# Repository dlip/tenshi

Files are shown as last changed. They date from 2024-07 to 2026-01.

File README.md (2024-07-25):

# Tenshi Keyboard

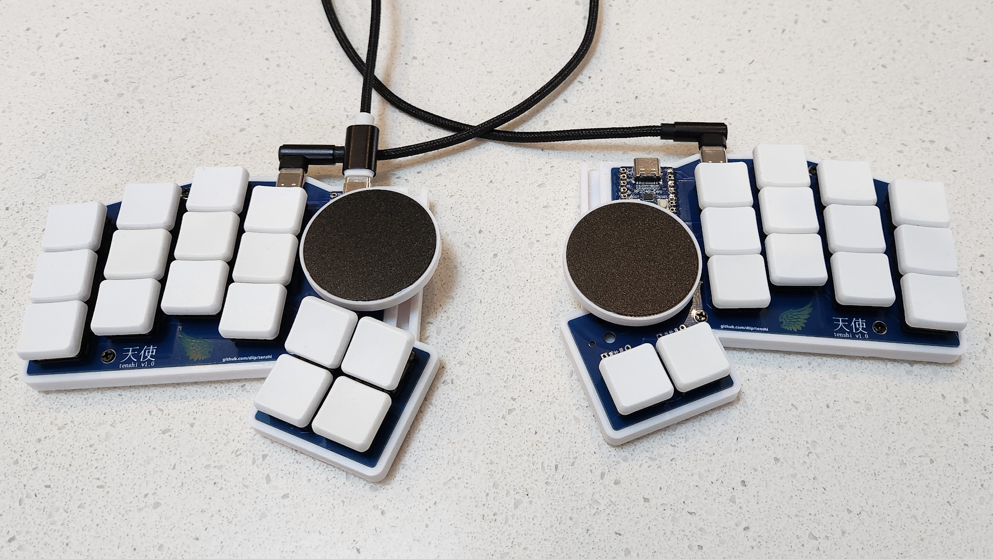
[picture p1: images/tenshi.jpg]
Tenshi


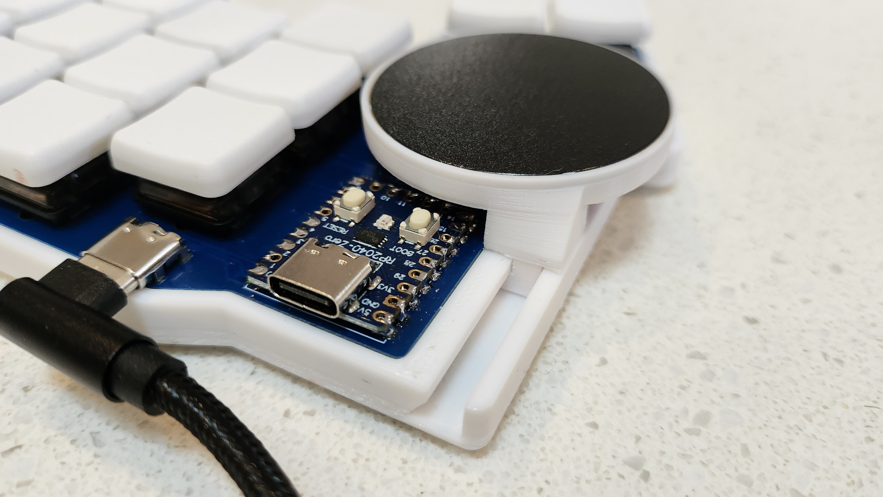
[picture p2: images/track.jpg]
Track


- RP2040-Zero controllers
- Split using USB-C to connect the halves
- Slide-adjustable Dual Cirque 40mm trackpads
- [QMK Firmware](https://github.com/dlip/qmk_firmware/tree/dlip/keyboards/tenshi)
- Custom PCB and case
- Name from Japanese means angel (the trackpads are the halos)

## BOM

- PCBs - send the [Gerber](kicad/gerber_to_order) file to the PCB manufacturer of your choice
- 2 x RP2040-Zero
- 2 x HRO TYPE-C-31-M-12 USB C female ports
- 2 x USB-C cables
- 0-2 x Cirque 40mm Trackpads TM040040-2024-302 with flat overlay
- 0-2 x Hirose FH12-12S-0.5SH FFC/FPC connectors
- 0-2 FFC/FPC cables - 5cm length, 12 position, 0.5mm pitch, same-sided contacts
- 32 x 1N4148 SOD-123 Diodes
- 32 x kailh hotswap sockets
- 32 x low profile choc switches and keycaps
- 6 x Knurled Insert Nuts M2 x 3mm Length x 3.5mm outer diameter
- 6 x M2 4mm flat head screws
- 8 x Rubber feet

## Printables

The .stls are in the [printables](./printables) folder and there is also the [OnShape Project](https://cad.onshape.com/documents/9fc41580bdc06f2de5a54d4e/w/2ac3b2b1ad9676183a17550a/e/836a95015accbfb788e70834) in case you want to make modifications.

## Build Pics

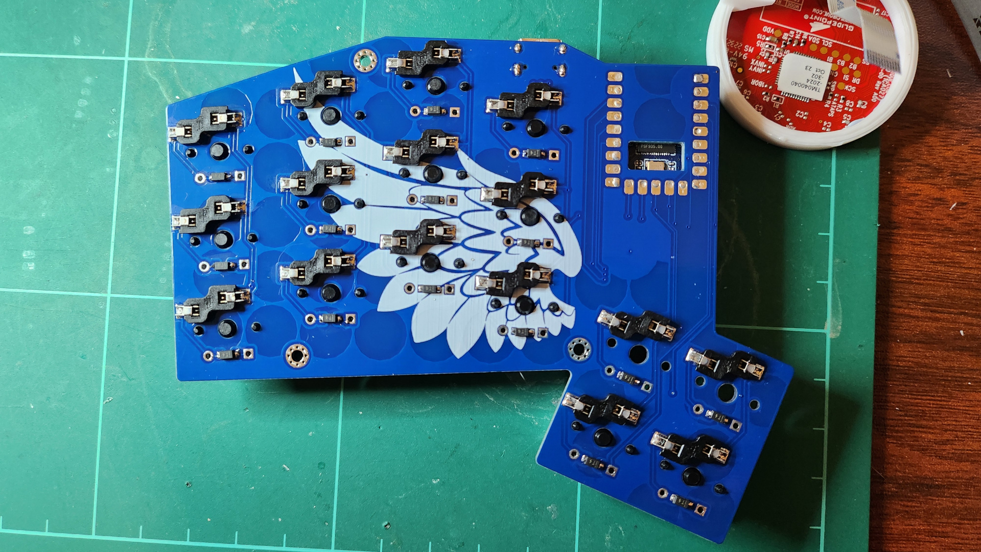
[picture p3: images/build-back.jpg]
Back


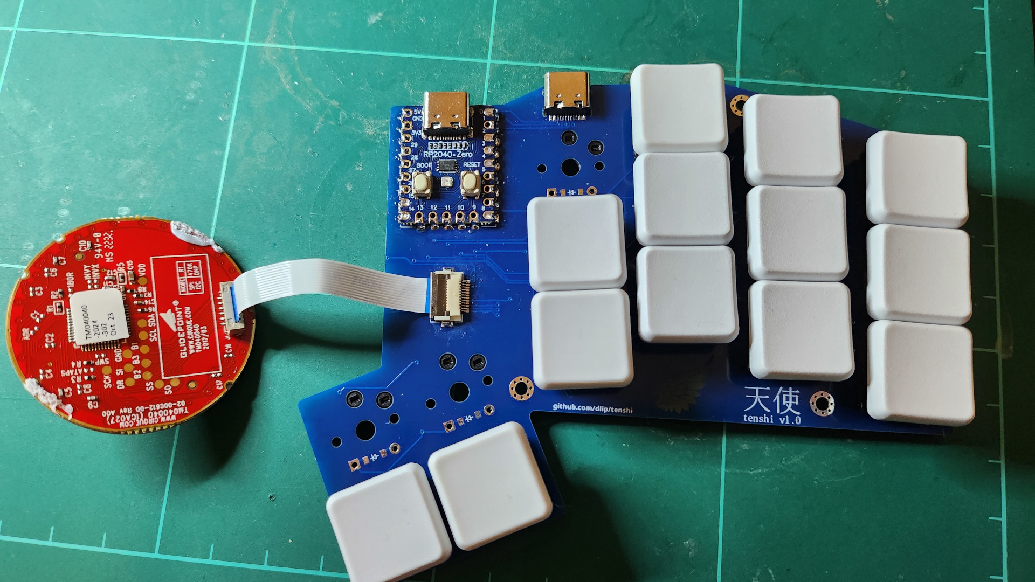
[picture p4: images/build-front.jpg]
Front


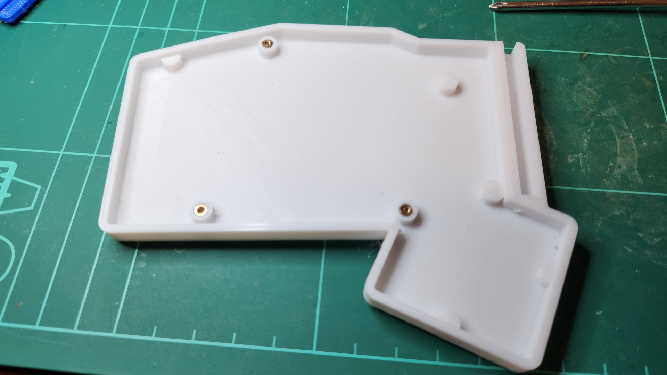
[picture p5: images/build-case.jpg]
Case


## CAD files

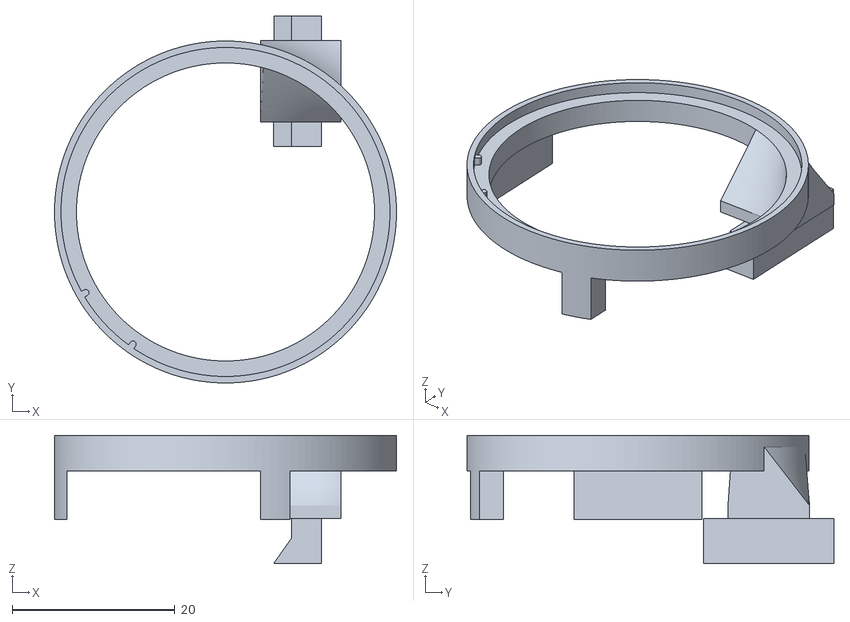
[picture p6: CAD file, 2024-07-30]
printables/Cirque trackpad left.stl
42.0 x 45.1 x 15.7

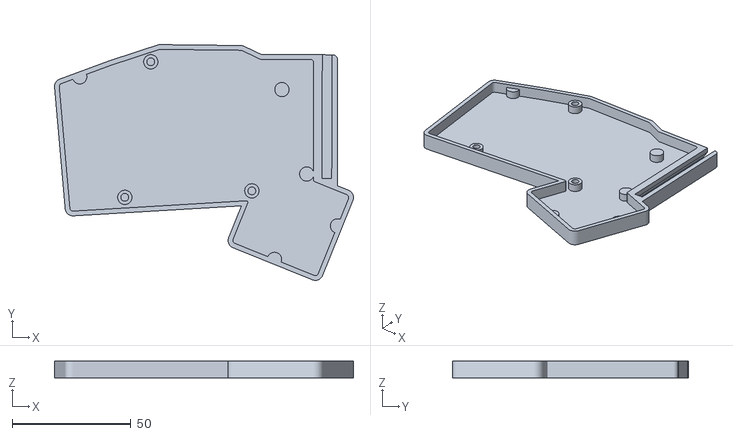
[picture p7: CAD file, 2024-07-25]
printables/base left.stl
125.7 x 99.1 x 7.00

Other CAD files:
printables/Cirque trackpad right.stl
printables/base right.stl

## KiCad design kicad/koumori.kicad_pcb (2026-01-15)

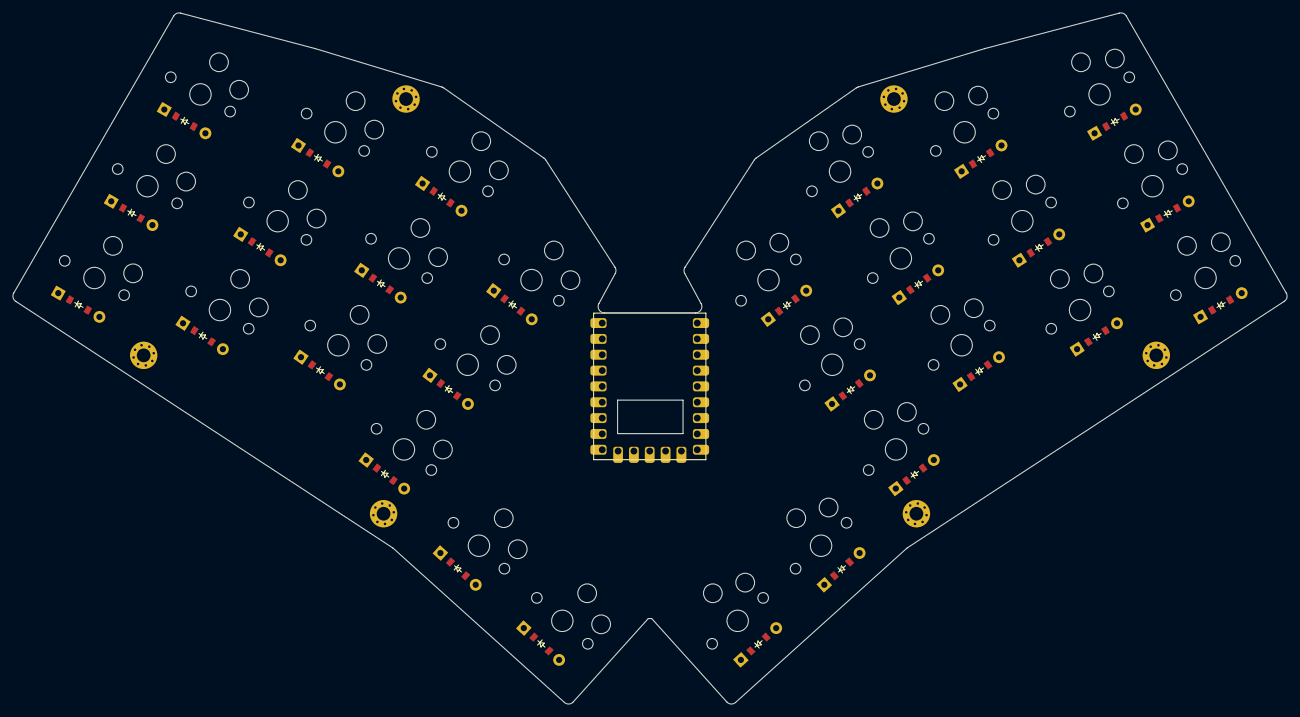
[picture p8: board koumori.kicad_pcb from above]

Board: 2 copper layers, 204.3 x 110.8 mm, 63 parts (0 on the bottom side), 39 nets, no tracks yet.

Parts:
D1, D2, D3, D4, D5, D6, D7, D8, D9, D10, D11, D12, D13, D14, D15, D16, D17, D18, D19, D20, D21, D22, D23, D24, D25, D26, D27, D28: ComboDiode
RP2040Zero1: RP2040-Zero
S1, S2, S3, S4, S5, S6, S7, S8, S9, S10, S11, S12, S13, S14, S15, S16, S17, S18, S19, S20, S21, S22, S23, S24, S25, S26, S27, S28: PG1350
_1, _2, _3, _4, _5, _6: MountingHole_2.2mm_M2_Pad_Via

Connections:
GP0: D17.1, D20.1, D23.1, D26.1, RP2040Zero1.1
GP1: D16.1, D19.1, D22.1, D25.1, RP2040Zero1.2
GP6: D15.1, D18.1, D21.1, D24.1, RP2040Zero1.7
GP7: D13.1, D14.1, D27.1, D28.1, RP2040Zero1.8
GP10: RP2040Zero1.11, S1.1, S2.1, S3.1, S15.1, S16.1, S17.1, S27.1
GP11: RP2040Zero1.12, S4.1, S5.1, S6.1, S18.1, S19.1, S20.1, S28.1
GP12: RP2040Zero1.13, S7.1, S8.1, S9.1, S14.1, S21.1, S22.1, S23.1
GP13: RP2040Zero1.14, S10.1, S11.1, S12.1, S13.1, S24.1, S25.1, S26.1
GP27: D1.1, D4.1, D7.1, D10.1, RP2040Zero1.18
GP28: D2.1, D5.1, D8.1, D11.1, RP2040Zero1.22
GP29: D3.1, D6.1, D9.1, D12.1, RP2040Zero1.23
index_bottom: D10.2, S10.2
index_middle: D11.2, S11.2
index_top: D12.2, S12.2
inner_top: D13.2, S13.2
middle_bottom: D7.2, S7.2
middle_middle: D8.2, S8.2
middle_top: D9.2, S9.2
mirror_index_bottom: D24.2, S24.2
mirror_index_middle: D25.2, S25.2
mirror_index_top: D26.2, S26.2
mirror_inner_top: D27.2, S27.2
mirror_middle_bottom: D21.2, S21.2
mirror_middle_middle: D22.2, S22.2
mirror_middle_top: D23.2, S23.2
mirror_outer_top: D28.2, S28.2
mirror_pinky_bottom: D15.2, S15.2
mirror_pinky_middle: D16.2, S16.2
mirror_pinky_top: D17.2, S17.2
mirror_ring_bottom: D18.2, S18.2
mirror_ring_middle: D19.2, S19.2
mirror_ring_top: D20.2, S20.2
outer_top: D14.2, S14.2
pinky_bottom: D1.2, S1.2
pinky_middle: D2.2, S2.2
pinky_top: D3.2, S3.2
ring_bottom: D4.2, S4.2
ring_middle: D5.2, S5.2
ring_top: D6.2, S6.2

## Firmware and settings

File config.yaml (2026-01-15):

units:
  # Proxy Spacing Variables
  kx: cx
  ky: cy
  # Padding Variables
  px: kx + 2
  py: ky + 2
  # Double Padding Variables
  dpx: kx + 8
  dpy: ky + 8
  # M2 Screw Inserts
  screwRadius: 1.50
  standoffRadius: 3
  # Footprints
  rp2040zero_x: 18
  rp2040zero_y: 23.5
  fpc_x: 5
  fpc_y: 11
points:
  zones:
    matrix:
      mirror: &mirror
        ref: matrix_index_top
        distance: 38
      anchor:
        shift: [30, -80]
      key:
        padding: 1ky
        spread: 1kx
      columns:
        pinky:
          key:
            splay: -30
            column_net: GP10
            mirror.column_net: GP10
        ring:
          key:
            stagger: 0.33ky
            splay: -3
            spread: 1kx + 2
            column_net: GP11
            mirror.column_net: GP11
        middle:
          key:
            stagger: 0.33ky
            splay: -2
            spread: 1kx + 1
            column_net: GP12
            mirror.column_net: GP12
        index:
          key:
            stagger: -0.45ky
            splay: -2
            spread: 1kx + 0.2
            column_net: GP13
            mirror.column_net: GP13
      rows:
        bottom:
          row_net: GP27
          mirror.row_net: GP6
        middle:
          row_net: GP28
          mirror.row_net: GP1
        top:
          row_net: GP29
          mirror.row_net: GP0
    thumbs:
      mirror: *mirror
      key:
        padding: 1ky
        spread: 1kx
      anchor:
        ref: matrix_index_bottom
        shift: [1.05kx, -.3ky]
      columns:
        inner:
          key:
            splay: -5
            column_net: GP13
            mirror.column_net: GP10
        outer:
          key:
            column_net: GP12
            mirror.column_net: GP11
      rows:
        top:
          row_net: GP7
          mirror.row_net: GP7
    mcu:
      anchor:
        aggregate.parts: [matrix_index_top, mirror_matrix_index_top]
        shift: [0, -17]
      key:
        width: rp2040zero_x
        height: rp2040zero_y
    cirque:
      anchor:
        aggregate.parts: [matrix_index_top, mirror_matrix_index_top]
        shift: [0, -26.3]
      key:
        width: rp2040zero_x
        height: rp2040zero_y
    fpc:
      anchor:
        ref: mcu
        shift: [.89kx, -.5ky]
      key:
        width: fpc_x
        height: fpc_y
    holeRingTop:
      mirror: *mirror
      anchor:
        ref: [matrix_ring_top]
        shift: [0.33px, 0.56py]
    holeRingBottom:
      mirror: *mirror
      anchor:
        ref: [matrix_ring_bottom]
        shift: [-0.35kx, -0.75ky]
    holeOuterThumbs:
      mirror: *mirror
      anchor:
        ref: [matrix_index_bottom]
        shift: [0.2kx, -0.6ky]
outlines:
  keys:
    - what: rectangle
      where: /matrix|thumb/
      size: [kx-0.5, ky-0.5]
  boardLeft:
    - what: polygon
      operation: stack
      fillet: 1
      points:
        - ref: matrix_pinky_top
          shift: [-0.5px, 0.5py]
        - ref: matrix_ring_top
          shift: [-0.5px, 0.5py]
        - ref: matrix_middle_top
          shift: [-0.5px, 0.5py]
        - ref: matrix_middle_top
          shift: [0.5px, 0.5py]
        - ref: matrix_index_top
          shift: [0.5px, 0.5py]
        - ref: mcu
          shift: [-rp2040zero_x/2, rp2040zero_y/2]
        - ref: mcu
          shift: [rp2040zero_x/2, rp2040zero_y/2]
        - ref: mirror_matrix_index_top
          shift: [0.5px, 0.5py]
        - ref: mirror_matrix_middle_top
          shift: [0.5px, 0.5py]
        - ref: mirror_matrix_middle_top
          shift: [-0.5px, 0.5py]
        - ref: mirror_matrix_ring_top
          shift: [-0.5px, 0.5py]
        - ref: mirror_matrix_pinky_top
          shift: [-0.5px, 0.5py]
        - ref: mirror_matrix_pinky_bottom
          shift: [-0.5px, -0.5py]
        - ref: mirror_thumbs_inner_top
          shift: [-0.5px, -0.5py]
        - ref: mirror_thumbs_outer_top
          shift: [0.5px, -0.5py]
        - ref: mirror_thumbs_outer_top
          shift: [0.5px, 0.5py]
        - ref: mirror_thumbs_outer_top
          shift: [0.5px, 0.5py]
        - ref: thumbs_outer_top
          shift: [0.5px, 0.5py]
        - ref: thumbs_outer_top
          shift: [0.5px, 0.5py]
        - ref: thumbs_outer_top
          shift: [0.5px, -0.5py]
        - ref: thumbs_inner_top
          shift: [-0.5px, -0.5py]
        - ref: matrix_pinky_bottom
          shift: [-0.5px, -0.5py]
  board:
    - boardLeft
  _mcu:
    - what: rectangle
      where: /^mcu/
      size: [rp2040zero_x, rp2040zero_y]
  _fpc:
    - what: rectangle
      where: /fpc/
      size: [fpc_x, fpc_y]
  _cirque:
    - what: circle
      where: /cirque/
      radius: 20
  _cirque_outer:
    - what: circle
      where: /cirque/
      radius: 21
  _mountingLeft:
    - what: circle
      where: /^hole/
      radius: screwRadius
  _mountingRight:
    - what: circle
      where: /^mirror_hole/
      radius: screwRadius
  _standoffLeft:
    - what: circle
      where: /^hole/
      radius: standoffRadius
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

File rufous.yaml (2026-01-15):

units:
  # Parameters
  # ==========
  capx: cx        # Key cap size horizontal
  capy: cy        # Key cap size vertical
  kx: cx + 0.01    # Key spacing horizontal
  ky: cy + 0.01    # Key spacing vertical
  angle: 22       # Angle between halves
  pinky_stagger: 2/3ky
  pinky_splay: 5  # Degrees of splay between pinky and ring columns
  pinky_adj: -3   # Adjustment to compensate for splay spacing
  ring_splay: 3
  ring_adj: -8

  # Constants
  # =========
  pcb_x: 18
  pcb_y: 23.5
  visual_x: 1     # Visual representation of keycaps horizontal
  visual_y: 1     # Visual representation of keycaps vertical
  sf: 16          # Switch footprint (square)

points:
  zones.matrix:
    rotate: -angle + pinky_splay + ring_splay
    mirror: &mirror
      ref: matrix_index_top
      shift: [0.5sf, 0.5sf]
      distance: 13
    key: &key
      width: capx
      height: capy
      autobind: false      
      tags:
        keys: true
      footprints:
      - type: choc
        nets:
          from: =row_net
          to: =column_net
        params:
          keycaps: true
    rows:
      bottom.padding: ky
      home.padding: ky
      top.padding: ky
    columns.pinky:
      key.spread: kx
      rows:
        bottom.skip: true
        home:
          bind: [0.5ky, 0.5kx, 0, 0]
          row_net: P2
          column_net: P6
        top:
          bind: [0, 0.5kx, 0.5ky, 0]
          row_net: P0
          column_net: P6
        home.mirror:
          row_net: P3
          column_net: P10
        top.mirror:
          row_net: P1
          column_net: P10
    columns.ring:
      key:
        spread: kx
        stagger: pinky_stagger
        splay: -pinky_splay
        origin: [0, pinky_adj]
      rows:
        bottom:
          bind: [0.5ky, 0, 0, 0]
          row_net: P4
          column_net: P6
        home:
          bind: [0, 0.5kx, 0, 0]
          row_net: P3
          column_net: P6
        top:
          bind: [0, 0.5kx, 0.5ky, 0]
          row_net: P1
          column_net: P6
        bottom.mirror:
          row_net: P5
          column_net: P9
        home.mirror:
          row_net: P2
          column_net: P10
        top.mirror:
          row_net: P0
          column_net: P10
    columns.middle:
      key:
        spread: kx
        stagger: 0.25ky
        splay: -ring_splay
        origin: [0, ring_adj]
      rows:
        bottom:
          bind: [0.5ky, 0.5kx, 0, 0.5kx]
          row_net: P5
          column_net: P6
        home:
          bind: [0, 0.5kx, 0, 0]
          row_net: P2
          column_net: P7
        top:
          bind: [0, 0, 0.5ky, 0]
          row_net: P0
          column_net: P7
        bottom.mirror:
          row_net: P4
          column_net: P9
        home.mirror:
          row_net: P3
          column_net: P9
        top.mirror:
          row_net: P1
          column_net: P9
    columns.index:
      key:
        spread: kx
        stagger: -0.25ky
      rows:
        bottom:
          bind: [0.5ky, 0, 0, 0]
          row_net: P4
          column_net: P7
        home:
          row_net: P3
          column_net: P7
        top:
          bind: [0, 0, 0.5ky, 0.5kx]
          row_net: P1
          column_net: P7
        bottom.mirror:
          row_net: P5
          column_net: P8
        home.mirror:
          row_net: P2
          column_net: P9
        top.mirror:
          row_net: P0
          column_net: P9
  zones.thumb:
    anchor:
      ref: matrix_index_bottom
      shift: [0.25kx, -22]
    mirror: *mirror
    key: *key
    columns:
      tucky:
        key:
          name: thumb_tucky
          bind: [0.5ky, 0.5kx, 0, 0]
          row_net: P5
          column_net: P7
        key.mirror:
          row_net: P4
          column_net: P10
      reachy:
        key:
          spread: kx
          stagger: -0.25ky        
          name: thumb_reachy
          bind: [1.5ky, 0, 0, 0]
          row_net: P4
          column_net: P8
        key.mirror:
          row_net: P5
          column_net: P10
  zones.mcu:
    anchor:
      aggregate.parts: [matrix_index_top, mirror_matrix_index_top]
      shift: [0, -0.7ky - 0.5pcb_y]
    key:
      name: mcu
      width: pcb_x
      height: pcb_y
      footprints:
      - type: pcb
        anchor:
          shift: [-0.5pcb_x, -0.5pcb_y]  # Anchor is topleft corner
  zones.mounting_hole:
    anchor:
      ref: matrix_index_home
      shift: [-0.5kx + 4, -ky + 4]
    mirror: *mirror
    key:
      name: mounting_hole
      width: 1
      height: 1
      footprints:
      - type: mountinghole
outlines:
    _key_outline:
      - what: rectangle
        bound: true
        size: sf
        where: [keys]
    _center:
      - what: polygon
        points:
        - ref: matrix_index_top
          shift: [0, -0.7ky]
        - ref: mirror_matrix_index_top
          shift: [0, -0.7ky]
        - ref: mirror_thumb_reachy
        - ref: thumb_reachy
      - what: rectangle
        bound: true
        size: sf
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

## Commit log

2024-07-13 Add bom
2024-07-13 Add logo
    [HRO_TYPE-C-31-M-12.step, tenshi.kicad_pcb]
2024-07-13 Add url
    [tenshi.kicad_pcb]
2024-07-13 change fill
    [tenshi.kicad_pcb]
2024-07-13 Add gerbers
    [tenshi.kicad_pcb]
2024-07-25 Add printables
    [Cirque trackpad left.stl, Cirque trackpad right.stl, base left.stl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]
2024-07-30 Add support to trackpad
    [Cirque trackpad left.stl, Cirque trackpad right.stl]
